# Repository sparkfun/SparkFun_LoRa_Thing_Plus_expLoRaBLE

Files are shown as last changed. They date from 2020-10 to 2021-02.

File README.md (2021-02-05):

SparkFun LoRa Thing Plus - expLoRaBLE
========================================

SparkFun LoRa Thing Plus - expLoRaBLE

[*SparkFun LoRa Thing Plus - expLoRaBLE (WRL-17506)*](https://www.sparkfun.com/products/17506)

The SparkFun LoRa Thing Plus - expLoRaBLE is a wireless development board in Thing Plus form factor that includes the NM180100 LoRa® Bluetooth® 5 Low Energy SiP. It is a global IoT solution ideal for long range, low power applications combining the transmit power of Semtech's LoRa® SX1262 with the processing power of Ambiq Micro's Apollo3 Blue.

Repository Contents
-------------------

* **/Documentation** - Data sheets, additional product information
* **/Hardware** - Eagle design files (.brd, .sch)
* **/Hardware/Production** - Production panel files (.brd)

Documentation
--------------
* **[Hookup Guide](https://learn.sparkfun.com/tutorials/sparkfun-explorable-hookup-guide)** - Basic hookup guide for the [LoRa Thing Plus - expLoRaBLE](https://www.sparkfun.com/products/17506).

License Information
-------------------

This product is _**open source**_! 

Please review the LICENSE.md file for license information. 

If you have any questions or concerns on licensing, please contact technical support on our [SparkFun forums](https://forum.sparkfun.com/viewforum.php?f=152).

Distributed as-is; no warranty is given.

- Your friends at SparkFun.

_<COLLABORATION CREDIT>_

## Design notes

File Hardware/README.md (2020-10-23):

SparkFun LoRa Thing Plus - expLoRaBLE Design Files
=====================================

The .sch and .brd files hare are Eagle CAD schematic and PCB design files from SparkFun Electronics.
A freeware version of Autodesk Eagle can be found [here](https://www.autodesk.com/products/eagle/free-download).

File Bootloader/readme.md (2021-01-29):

## Programming info0 binary

Note, to program info0 properly, do these things:

1. Clone this repo.
2. Open a CMD window.
3. Navigate to the bootloader directory of this repo.
4. Run JLINK with the included commandfile like so:

* *"C:\Program Files (x86)\SEGGER\JLink\jlink.exe" -CommanderScript jlink-prog-info0.txt*

## Special notes about programming

* You cannot effectively program info0 binaries using J-flash Light GUI. You must use JLINK commander with a commandfile. A command file can include calls to "ROM helper functions", which are essential to correctly (actually) programming the info0 memory locations on the MCU. [This screenshot](https://github.com/sparkfun/SparkFun_LoRa_Thing_Plus_expLoRaBLE/blob/master/Documentation/programming_script_screenshot_highligh.png) shows the commands to the ROM helper functions.

* You can call Jlink.exe from command line with the commandfile as an argument. Note, you may have to include the complete paths to jlink.exe and the commanderfile. Also note, you need to navigate your CMD into this directory first.

* *C:\Users\pete.lewis\Documents\GitHub\SparkFun_LoRa_Thing_Plus_expLoRaBLE\Bootloader>"C:\Program Files (x86)\SEGGER\JLink\jlink.exe" -CommanderScript jlink-prog-info0.txt*

This is the readout you should see:

    C:\Users\pete.lewis\Documents\GitHub\SparkFun_LoRa_Thing_Plus_expLoRaBLE\Bootloader>"C:\Program Files (x86)\SEGGER\JLink\jlink.exe" -CommanderScript jlink-prog-info0.txt
    SEGGER J-Link Commander V6.92 (Compiled Dec 18 2020 13:13:50)
    DLL version V6.92, compiled Dec 18 2020 13:12:28

    J-Link Command File read successfully.
    Processing script file...

    J-Link connection not established yet but required for command.
    Connecting to J-Link via USB...O.K.
    Firmware: J-Link EDU Mini V1 compiled Nov 12 2020 13:31:42
    Hardware version: V1.00
    S/N: 801028773
    License(s): FlashBP, GDB
    VTref=3.283V

    Selecting SWD as current target interface.

    Selecting 1000 kHz as target interface speed

    Target connection not established yet but required for command.
    Device "AMA3B1KK-KBR" selected.

    Connecting to target via SWD
    Found SW-DP with ID 0x2BA01477
    DPIDR: 0x2BA01477
    Scanning AP map to find all available APs
    AP[1]: Stopped AP scan as end of AP map has been reached
    AP[0]: AHB-AP (IDR: 0x24770011)
    Iterating through AP map to find AHB-AP to use
    AP[0]: Core found
    AP[0]: AHB-AP ROM base: 0xE00FF000
    CPUID register: 0x410FC241. Implementer code: 0x41 (ARM)
    Found Cortex-M4 r0p1, Little endian.
    FPUnit: 6 code (BP) slots and 2 literal slots
    CoreSight components:
    ROMTbl[0] @ E00FF000
    ROMTbl[0][0]: E000E000, CID: B105E00D, PID: 000BB00C SCS-M7
    ROMTbl[0][1]: E0001000, CID: B105E00D, PID: 003BB002 DWT
    ROMTbl[0][2]: E0002000, CID: B105E00D, PID: 002BB003 FPB
    ROMTbl[0][3]: E0000000, CID: B105E00D, PID: 003BB001 ITM
    ROMTbl[0][4]: E0040000, CID: B105900D, PID: 000BB9A1 TPIU
    Cortex-M4 identified.
    Reset delay: 0 ms
    Reset type NORMAL: Resets core & peripherals via SYSRESETREQ & VECTRESET bit.
    ResetTarget() start
    JDEC PID 0x000000CF
    Ambiq Apollo3 ResetTarget
    Bootldr = 0x04000000
    Secure Part.
    Secure Chip. Bootloader needs to run which will then halt when finish.
    CPU halted after reset. TryCount = 0x00000000
    ResetTarget() end

    Sleep(10)

    MSP = 0x10000100

    Writing 00000000 -> 10000000

    Writing D894E09E -> 10000004

    Writing FFFFFFFF -> 10000008

    Sleep(50)

    10000008 = 00000000

    Writing 00000000 -> 10000000

    Writing 00000000 -> 10000004

    Writing 00000800 -> 10000008

    Writing D894E09E -> 1000000C

    Writing FFFFFFFF -> 10000010

    Downloading file [info0_115200_bootGPIO22_active_high.bin]...
    O.K.

    Sleep(50)

    10000010 = 00000000

    Writing 0000001B -> 40000004

    Script processing completed.

## Info0 binary creation info

This was used to create the info0 file to work with the Ambiq Secure Bootloader in the expLoRaBLE design:

    python create_info0.py --valid 1 info0_115200_gpio22_active_high --pl 1 --u0 0x1c200c0 --u1 0xFFFF3031 --u2 0x2 --u3 0x0 --u4 0x0 --u5 0x0 --main 0xC000 --gpio 0x16 --version 0 --wTO 2500 --gpiolvl 1 --chip apollo3

Where:
* --u0 0x1C200c0 = 115200 baud (0x1c200)
* --main 0xC000 = main image location (0xC000)
* -- u1 0xFFFF3031 = UART-TX (0x30 - pin 48) and UART-RX (0x31 - pin 49)
* --gpio 0x16 = GPIO override *for the boot pin* (0x16, GPIO22)
* --gpiolvl 1 = active high boot setup (note, the default is active low, and the only SFE design as of 1/29/2021 that had active low was the edge, all others (e.g. the artemis and expLoRaBLE) are active high setups)
* --wTO 2500 = timeout failures set to 2500ms

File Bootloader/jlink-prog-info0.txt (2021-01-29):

// connect to device
// NEED to specify -device AMA3B2KK-KBR (for Apollo3P) or -device AMA3B1KK-KBR/KCR (for Apollo3) from command line

device AMA3B1KK-KBR

si SWD
speed 1000
r
sleep 10

//set C runtime environment
wreg MSP, 0x10000100 

// erase info0
w4 0x10000000 0             // flash info instance
w4 0x10000004 0xd894e09e    // info 0 key
w4 0x10000008 0xFFFFFFFF    // clear return value
setPC 0x08000085            // call the ROM helper function flash_info_erase_from_sram
g
sleep 50
mem32 0x10000008 1          // dump return value for check

// program info0
w4 0x10000000 0             // flash info instance
w4 0x10000004 0             // offset
w4 0x10000008 0x800         // length in words
w4 0x1000000C 0xd894e09e    // info 0 key
w4 0x10000010 0xFFFFFFFF    // clear return value
loadbin info0_115200_bootGPIO22_active_high.bin 0x10001000     //load the info0 binary into sram
setPC 0x08000061            // call the ROM helper function flash_program_info_area_from_sram
g
sleep 50
mem32 0x10000010 1          // dump return value for check

// perform software POI
w4 0x40000004 0x1B

// quit
qc

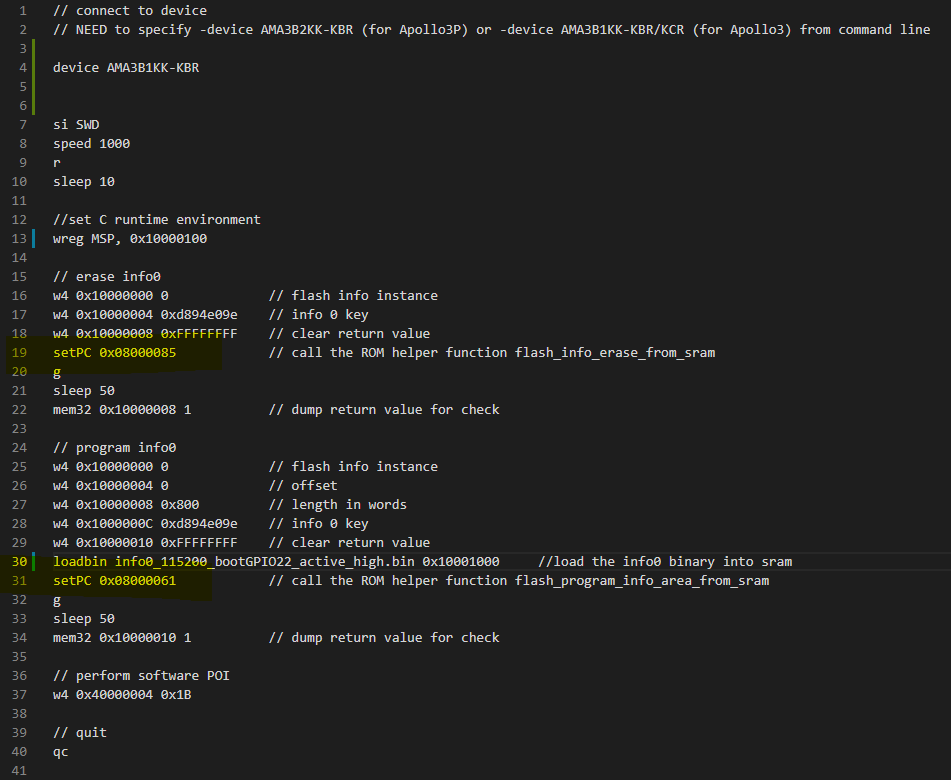
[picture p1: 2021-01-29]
Documentation/programming_script_screenshot_highligh.png

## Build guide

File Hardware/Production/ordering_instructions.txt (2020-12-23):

panel size, 131x201mm
PCB thickness, 1.6mm
number of layers, 4
soldermask color, Red
silkscreen color, White
oz copper, 1oz
finish, HASL lead free
stencils, top
pcs per panel, 15
min trace width, 0.1524mm / 0.0060in
min drill size, 0.2032mm / 0.0080in
filename to layer stackup 1/2/3/4: GTL, GL2, GL3, GBL

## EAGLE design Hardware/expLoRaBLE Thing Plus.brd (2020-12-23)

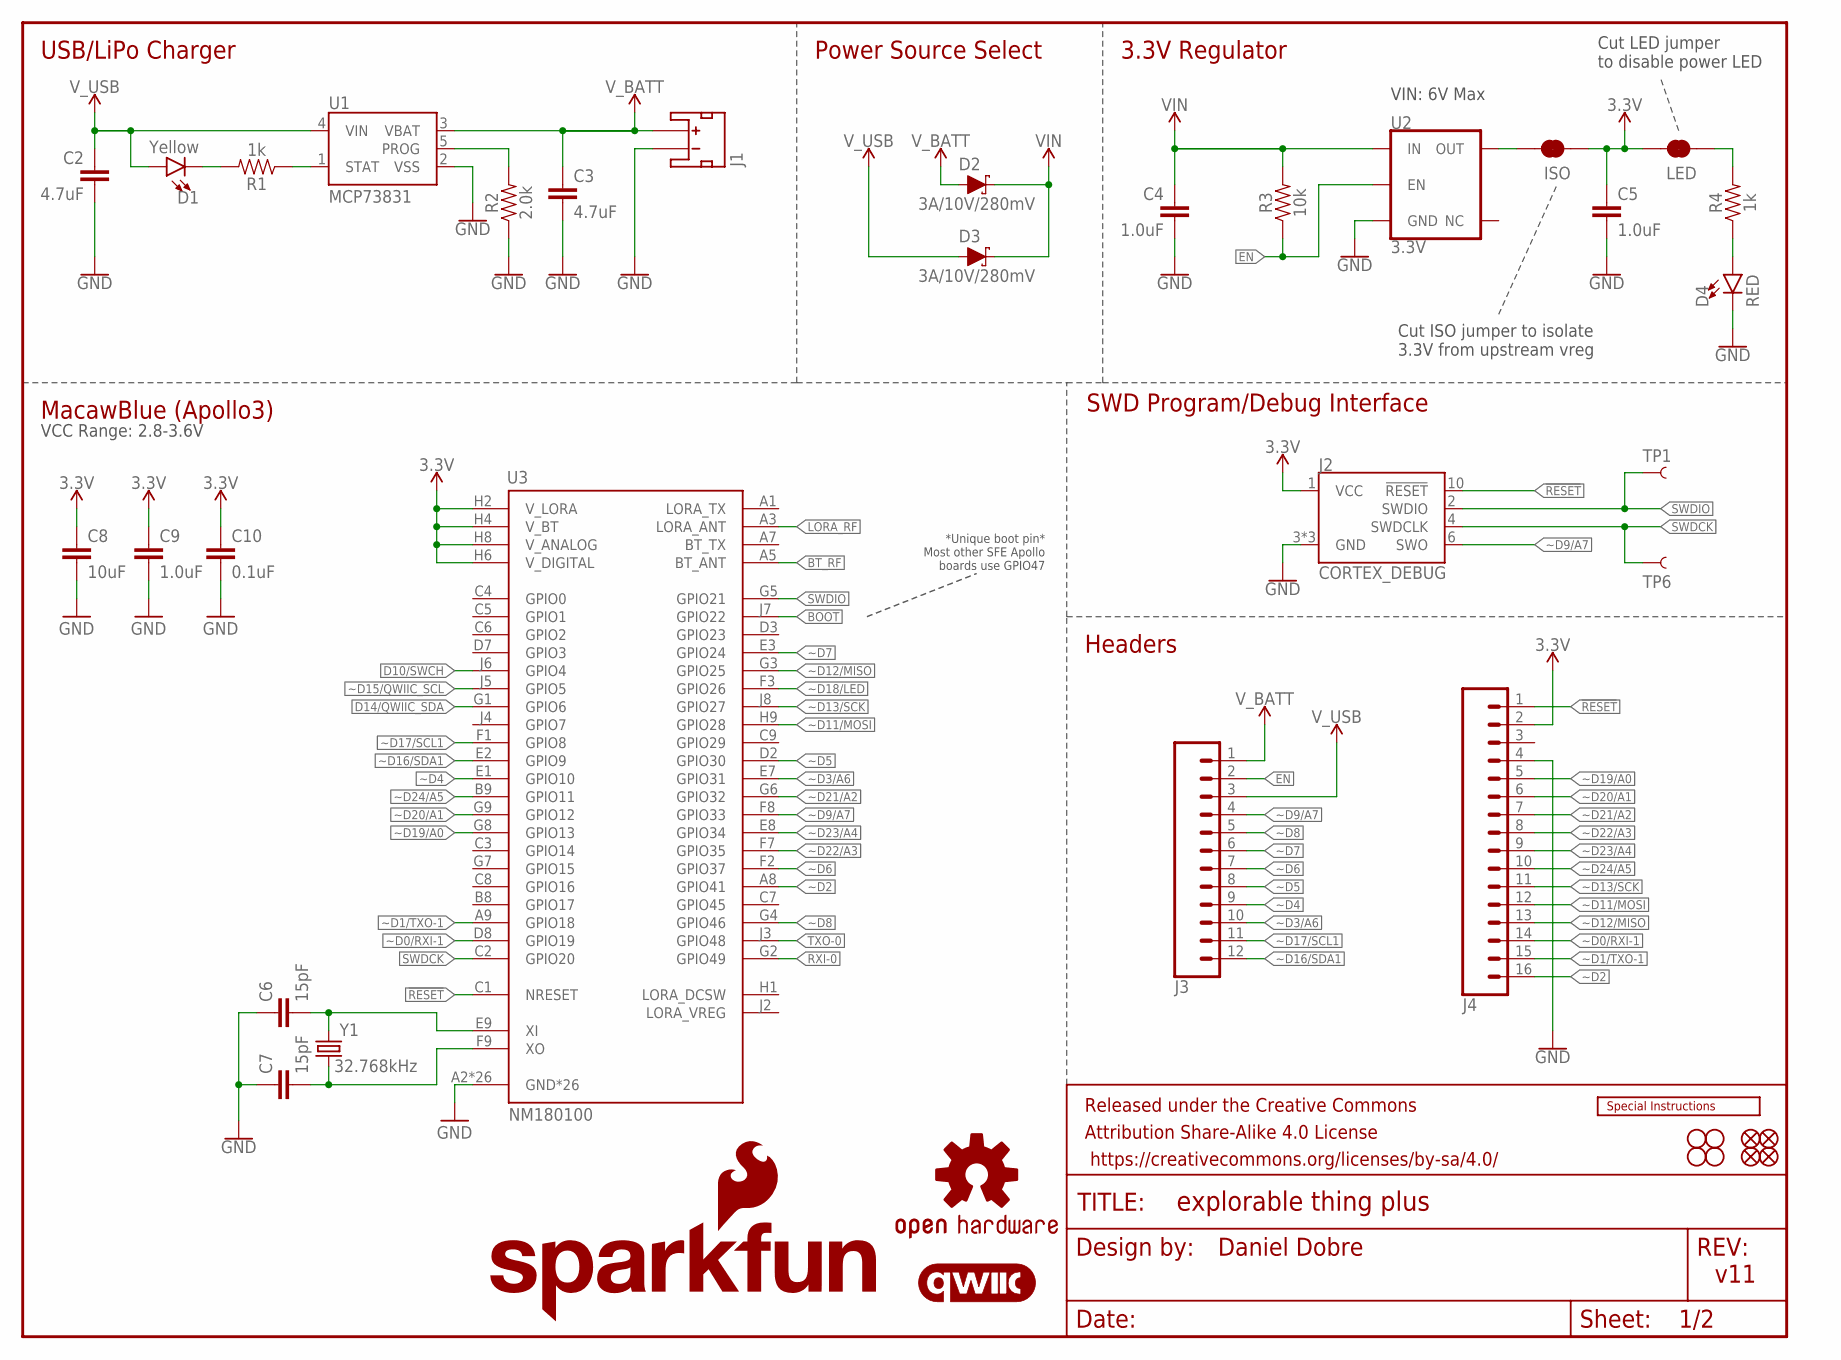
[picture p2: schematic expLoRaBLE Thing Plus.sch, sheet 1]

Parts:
C2, C3: 4.7uF; 0603
C4, C5, C9: 1.0uF; 0603
C6, C7: 15pF; 0603
C8: 10uF; 0603
C10: 0.1uF; 0603
D1: Yellow; LED-0603
D2, D3: 3A/10V/280mV; SOD-323
D4: RED; LED-0603
FD1, FD2, FD3, FD4: FIDUCIALUFIDUCIAL; FIDUCIAL-MICRO
FRAME1: FRAME-LETTER; CREATIVE_COMMONS
H1, H2, H3, H4: STAND-OFF
ISO: JUMPER-SMT_2_NC_TRACE_SILK; SMT-JUMPER_2_NC_TRACE_SILK
J1: JST_2MM_MALE; JST-2-SMD
J2: CORTEX_DEBUG; 2X5-PTH-1.27MM-NO_SILK
J3: CONN_12SM_SQ_NO_SILK; 1X12_SM_SQ_NOSILK
J4: CONN_161X16_SM_SQ_NOSILK; 1X16_SM_SQ_NOSILK
LED: JUMPER-SMT_2_NC_TRACE_SILK; SMT-JUMPER_2_NC_TRACE_SILK
LOGO1: OSHW-LOGOS; OSHW-LOGO-S
LOGO2: QWIIC_LOGO_5MM; QWIIC_5MM
LOGO3: SFE_LOGO_NAME_FLAME.1_INCH; SFE_LOGO_NAME_FLAME_.1
LOGO4: SPECIAL_INSTRUCTIONS-ORDERING; ORDERING_INSTRUCTIONS
R1, R4: 1k; 0603
R2: 2.0k; 0603
R3: 10k; 0603
TP1, TP6: TEST-POINTTP_15TH_THRU; TP_15TH
U1: MCP73831; SOT23-5
U2: 3.3V; SOT23-5
U3: NM180100; LGA81
Y1: 32.768kHz; CRYSTAL-SMD-3.2X1.5MM

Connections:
3.3V: C5.1, C8.1, C9.1, C10.1, ISO.1, J2.1 (VCC), J4.2, LED.2, U3.H2 (V_LORA), U3.H4 (V_BT), U3.H6 (V_DIGITAL), U3.H8 (V_ANALOG); also elsewhere on the board
!RESET: J2.10 (!RESET), J4.1, U3.C1 (NRESET); also elsewhere on the board
BOOT: U3.J7 (GPIO22); also elsewhere on the board
BT_RF: U3.A5 (BT_ANT); also elsewhere on the board
D10/SWCH: U3.J6 (GPIO4); also elsewhere on the board
D14/QWIIC_SDA: U3.G1 (GPIO6); also elsewhere on the board
EN: J3.2, R3.1, U2.3 (EN)
GND: C2.2, C3.2, C4.2, C5.2, C6.1, C7.1, C8.2, C9.2, C10.2, D4.C, J1.1 (-), J2.3 (GND), J2.5 (GND), J2.9 (GND), J4.4, R2.1, U1.2 (VSS), U2.2 (GND), U3.A2 (GND*26), U3.A4 (GND*26), U3.A6 (GND*26), U3.B1 (GND*26), U3.B2 (GND*26), U3.B3 (GND*26), U3.B4 (GND*26), U3.B5 (GND*26), U3.B6 (GND*26), U3.B7 (GND*26), U3.D1 (GND*26), U3.D4 (GND*26), U3.D5 (GND*26), U3.D6 (GND*26), U3.D9 (GND*26), U3.E4 (GND*26), U3.E5 (GND*26), U3.E6 (GND*26), U3.F4 (GND*26), U3.F5 (GND*26), U3.F6 (GND*26), U3.H3 (GND*26), U3.H5 (GND*26), U3.H7 (GND*26), U3.J1 (GND*26), U3.J9 (GND*26); also elsewhere on the board
LORA_RF: U3.A3 (LORA_ANT); also elsewhere on the board
unnamed: R2.2, U1.5 (PROG)
unnamed: C7.2, U3.F9 (XO), Y1.P$2 (2)
unnamed: D1.C, R1.2
unnamed: R1.1, U1.1 (STAT)
unnamed: LED.1, R4.2
unnamed: C6.2, U3.E9 (XI), Y1.P$1 (1)
unnamed: D4.A, R4.1
unnamed: ISO.2, U2.5 (OUT)
RXI-0: U3.G2 (GPIO49); also elsewhere on the board
SWDCK: J2.4 (SWDCLK), TP6.P$1, U3.C2 (GPIO20)
SWDIO: J2.2 (SWDIO), TP1.P$1, U3.G5 (GPIO21)
TXO-0: U3.J3 (GPIO48); also elsewhere on the board
VIN: C4.1, D2.C, D3.C, R3.2, U2.1 (IN)
V_BATT: C3.1, D2.A, J1.2 (+), J3.1, U1.3 (VBAT)
V_USB: C2.1, D1.A, D3.A, J3.3, U1.4 (VIN); also elsewhere on the board
~D0/RXI-1: J4.14, U3.D8 (GPIO19)
~D1/TXO-1: J4.15, U3.A9 (GPIO18)
~D2: J4.16, U3.A8 (GPIO41)
~D3/A6: J3.10, U3.E7 (GPIO31)
~D4: J3.9, U3.E1 (GPIO10)
~D5: J3.8, U3.D2 (GPIO30)
~D6: J3.7, U3.F2 (GPIO37)
~D7: J3.6, U3.E3 (GPIO24)
~D8: J3.5, U3.G4 (GPIO46)
~D9/A7: J2.6 (SWO), J3.4, U3.F8 (GPIO33)
~D11/MOSI: J4.12, U3.H9 (GPIO28)
~D12/MISO: J4.13, U3.G3 (GPIO25)
~D13/SCK: J4.11, U3.J8 (GPIO27)
~D15/QWIIC_SCL: U3.J5 (GPIO5); also elsewhere on the board
~D16/SDA1: J3.12, U3.E2 (GPIO9)
~D17/SCL1: J3.11, U3.F1 (GPIO8)
~D18/LED: U3.F3 (GPIO26); also elsewhere on the board
~D19/A0: J4.5, U3.G8 (GPIO13)
~D20/A1: J4.6, U3.G9 (GPIO12)
~D21/A2: J4.7, U3.G6 (GPIO32)
~D22/A3: J4.8, U3.F7 (GPIO35)
~D23/A4: J4.9, U3.E8 (GPIO34)
~D24/A5: J4.10, U3.B9 (GPIO11)

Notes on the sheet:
SWD Program/Debug Interface
Headers
MacawBlue (Apollo3)
USB/LiPo Charger
Power Source Select
3.3V Regulator
VIN: 6V Max
Daniel Dobre
v11
Cut LED jumper to disable power LED
Cut ISO jumper to isolate 3.3V from upstream vreg
VCC Range: 2.8-3.6V
*Unique boot pin* Most other SFE Apollo boards use GPIO47

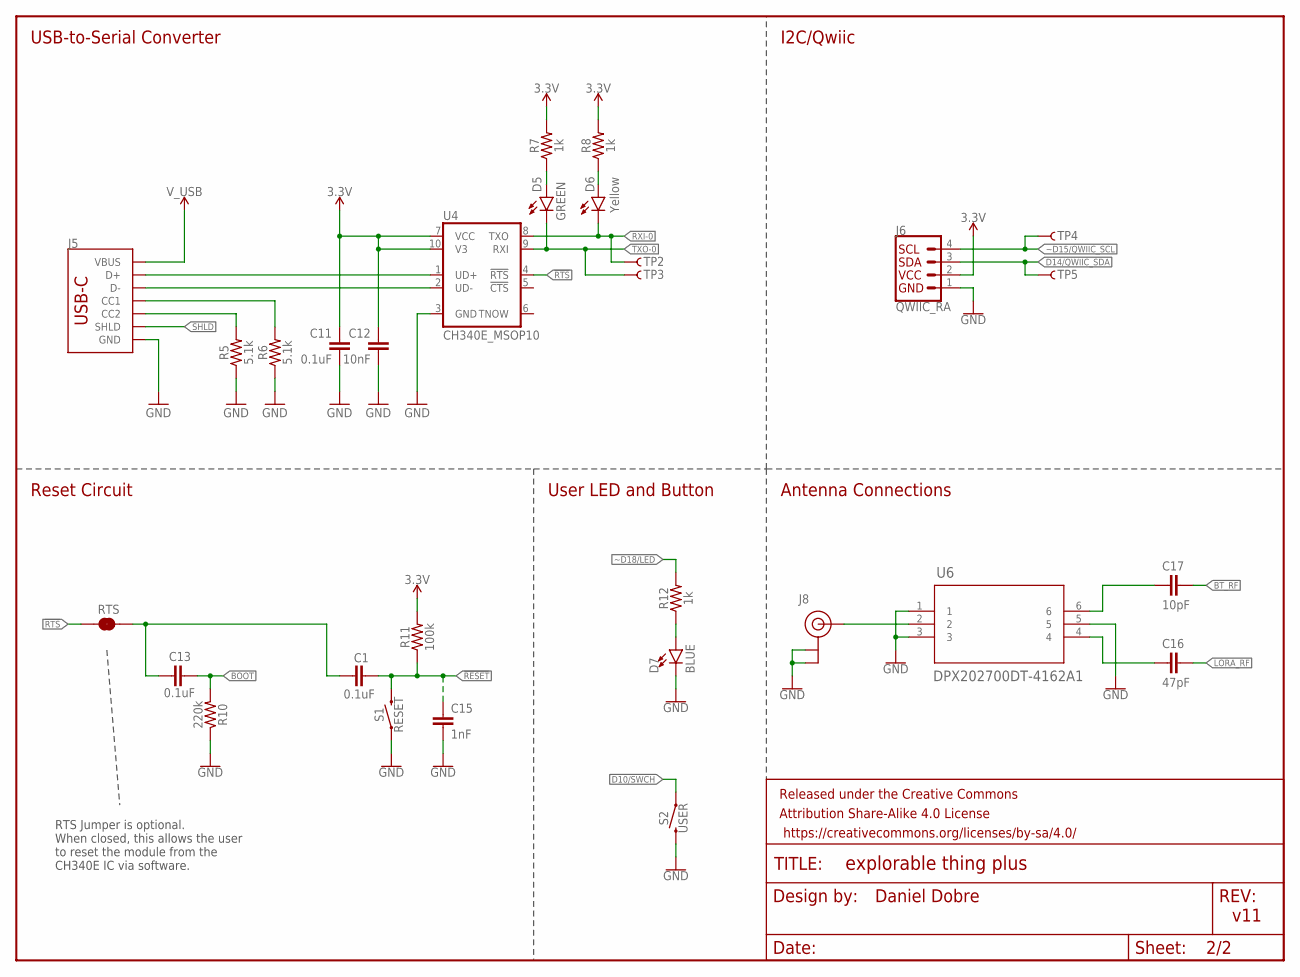
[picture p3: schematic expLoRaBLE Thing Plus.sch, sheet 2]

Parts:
C1, C11, C13: 0.1uF; 0603
C12: 10nF; 0603
C15: 1nF; 0603
C16: 47pF; 0603
C17: 10pF; 0603
D5: GREEN; LED-0603
D6: Yellow; LED-0603
D7: BLUE; LED-0603
FRAME2: FRAME-LETTERNO_PACKAGE; DUMMY
J5: USB Female Type C Connector; USB-C-16P-4LAYER-ISOLATED
J6: QWIIC_RA; JST04_1MM_RA
J8: U.FL
R5, R6: 5.1k; 0603
R7, R8, R12: 1k; 0603
R10: 220k; 0603
R11: 100k; 0603
RTS: JUMPER-SMT_2_NC_TRACE_SILK; SMT-JUMPER_2_NC_TRACE_SILK
S1: RESET; TACTILE_SWITCH_SMD_4.6X2.8MM
S2: USER; TACTILE_SWITCH_SMD_4.6X2.8MM
TP2, TP3, TP4, TP5: TEST-POINTTP_15TH_THRU; TP_15TH
U4: CH340E_MSOP10; MSOP10
U6: DPX202700DT-4162A1; RF_4060A1_TDK

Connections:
3.3V: C11.1, C12.1, J6.2, R7.2, R8.2, R11.2, U4.7 (VCC), U4.10 (V3); also elsewhere on the board
!RESET: C1.2, C15.1, R11.1, S1.3 (2), S1.4 (2); also elsewhere on the board
!RTS: RTS.1, U4.4 (!RTS)
BOOT: C13.2, R10.2; also elsewhere on the board
BT_RF: C17.1; also elsewhere on the board
CC1: J5.A5 (CC1), R6.2
CC2: J5.B5 (CC2), R5.2
D10/SWCH: S2.1, S2.2 (1); also elsewhere on the board
D14/QWIIC_SDA: J6.3, TP5.P$1; also elsewhere on the board
D+1: J5.A6 (D+), J5.B6 (D+), U4.1 (UD+)
D-1: J5.A7 (D-), J5.B7 (D-), U4.2 (UD-)
GND: C11.2, C12.2, C15.2, D7.C, J5.GND, J5.GND2 (GND), J6.1, J8.1 (GND), J8.2 (GND), R5.1, R6.1, R10.1, S1.1, S1.2 (1), S2.3 (2), S2.4 (2), U4.3 (GND), U6.1, U6.3, U6.5; also elsewhere on the board
LORA_RF: C16.1; also elsewhere on the board
unnamed: D5.A, R7.1
unnamed: D7.A, R12.1
unnamed: D6.A, R8.1
unnamed: C17.2, U6.6
unnamed: J8.FEED (SIGNAL), U6.2
unnamed: C16.2, U6.4
unnamed: C1.1, C13.1, RTS.2
RXI-0: D6.C, TP2.P$1, U4.8 (TXO); also elsewhere on the board
SHLD: J5.SHLD1 (SHLD), J5.SHLD2 (SHLD), J5.SHLD3 (SHLD), J5.SHLD4 (SHLD), J5.SHLD5 (SHLD), J5.SHLD6 (SHLD), J5.SHLD7 (SHLD), J5.SHLD8 (SHLD)
TXO-0: D5.C, TP3.P$1, U4.9 (RXI); also elsewhere on the board
V_USB: J5.VBUS1 (VBUS), J5.VBUS2 (VBUS); also elsewhere on the board
~D15/QWIIC_SCL: J6.4, TP4.P$1; also elsewhere on the board
~D18/LED: R12.2; also elsewhere on the board

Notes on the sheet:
Antenna Connections
USB-to-Serial Converter
Reset Circuit
User LED and Button
I2C/Qwiic
Daniel Dobre
v11
RTS Jumper is optional. When closed, this allows the user to reset the module from the CH340E IC via software.

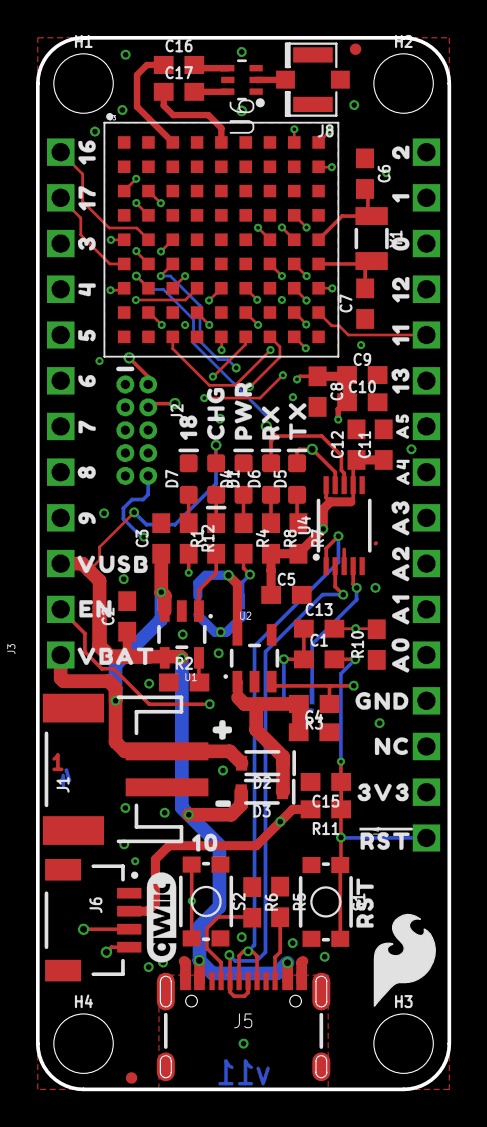
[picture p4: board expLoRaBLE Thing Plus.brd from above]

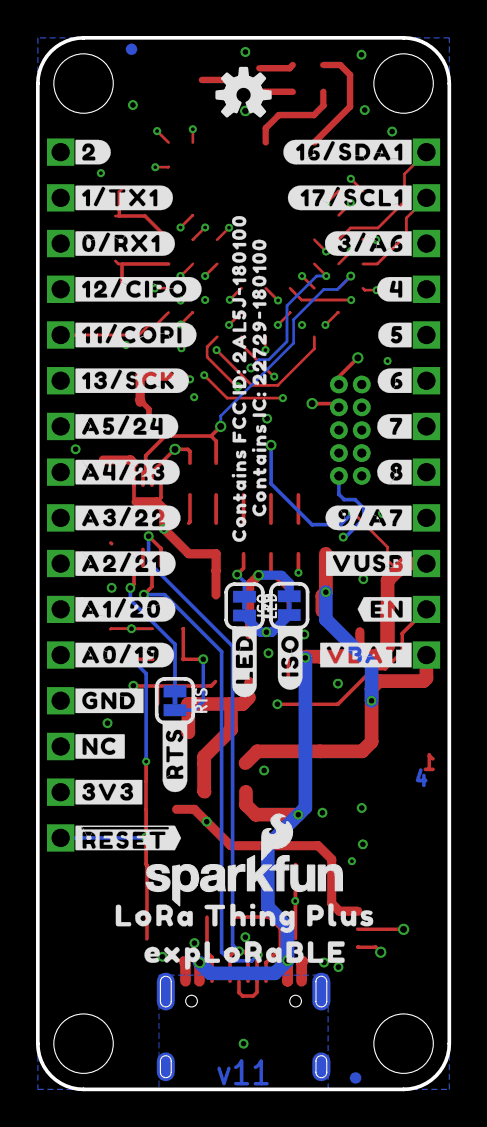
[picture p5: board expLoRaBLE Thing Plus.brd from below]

Board: 4 copper layers, 22.9 x 58.4 mm, 146 parts (42 on the bottom side), 60 nets.

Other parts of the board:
U$1: #16#SDA1#0
U$2: LORA_THING_PLUS0
U$3: EXPLORABLE0
U$4: #17#SCL1#0
U$5: #3#A6#0
U$6: #4#0
U$7: #5#0
U$8: #6#0
U$9: #7#0
U$10: #8#0
U$11: #9#A7#0
U$12: #VUSB#0
U$13: VUSB0
U$14: #EN#0
U$15: #VBAT#0
U$16: #2#0
U$17: #1#TX1#0
U$18: #0#RX1#0
U$19: #12#CIPO#0
U$20: #11#COPI#0
U$21: #13#SCK#0
U$22: CONTAINS_FCC_ID#_2AL5J#1801000
U$23: CONTAINS_IC#_22729#1801000
U$24: #RTS#0
U$28: #GND#0
U$29: #NC#0
U$30: #3V3#0
U$31: ##RESET##0
U$32: #LED#0
U$33: #A0#19#0
U$34: #ISO#0
U$35: #A1#20#0
U$36: #A2#21#0
U$37: #A3#22#0
U$38: #A4#23#0
U$39: #A5#24#0
U$62: 180
U$64: FOUR_LAYER_WARNING
U$65: SFE_LOGO_FLAME_.2
U$66: 160
U$67: CHG0
U$68: PWR0
U$69: 170
U$70: 30
U$71: 40
U$72: 50
U$73: 60
U$74: 70
U$75: 80
U$76: 90
U$78: EN0
U$79: VBAT0
U$80: 20
U$81: 10
U$82: 00
U$83: 120
U$84: 110
U$85: 130
U$86: A50
U$87: A40
U$88: A30
U$89: A20
U$90: A10
U$91: A00
U$92: GND0
U$93: NC0
U$94: 3V30
U$95: #RST#0
U$96: RST0
U$97: 100
U$98: #0
U$99: #_0
U$100: RX0
U$101: TX0

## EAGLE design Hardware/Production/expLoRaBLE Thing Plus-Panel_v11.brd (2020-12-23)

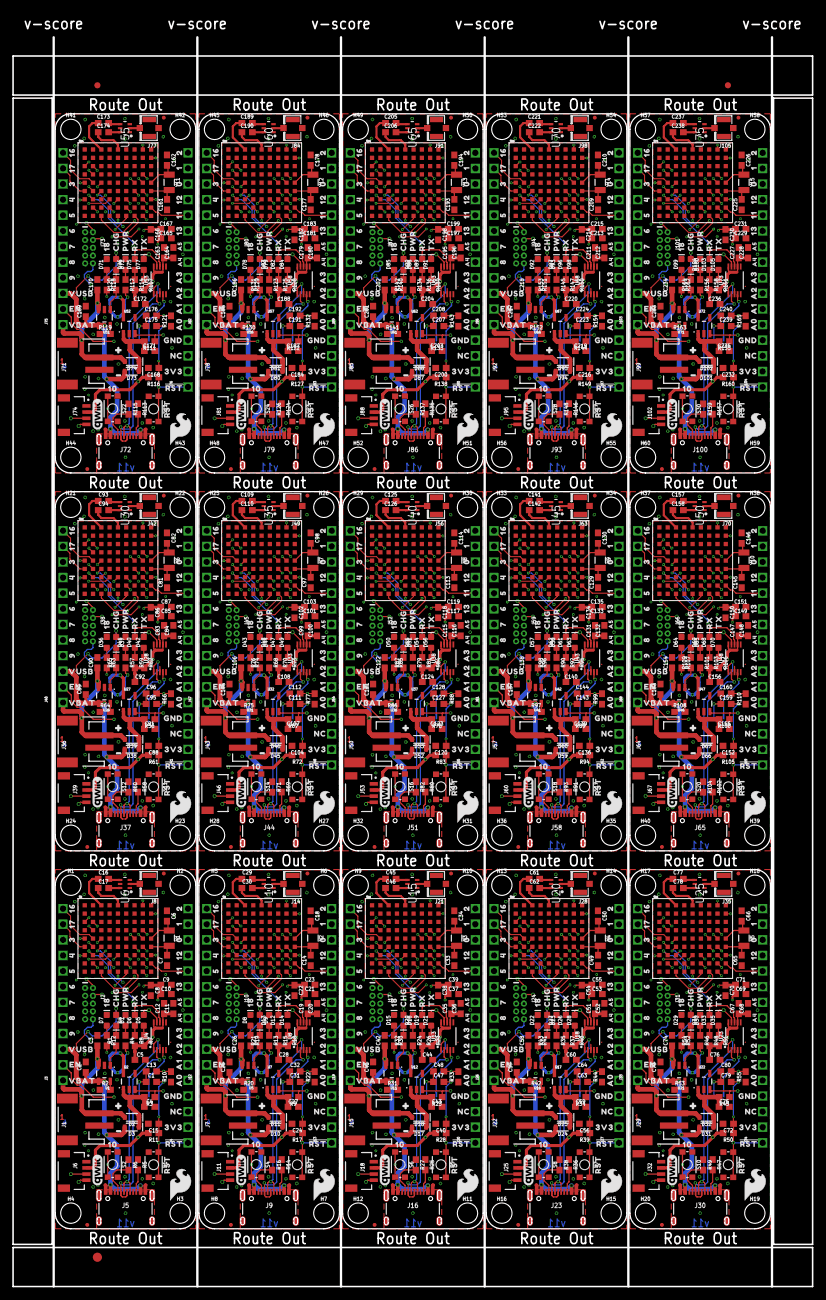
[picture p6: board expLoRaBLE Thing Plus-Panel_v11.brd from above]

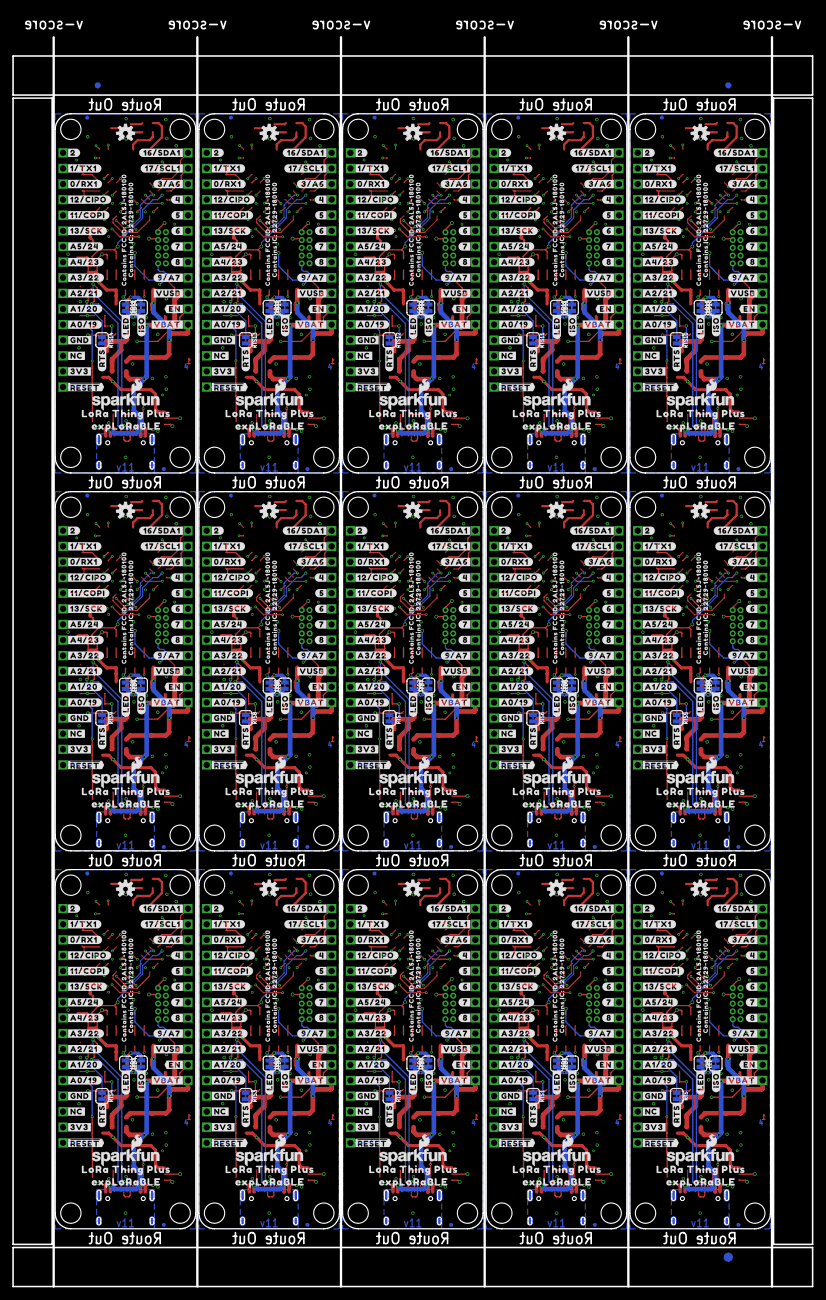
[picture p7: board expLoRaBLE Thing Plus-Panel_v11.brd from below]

Board: 4 copper layers, 130.0 x 203.2 mm, 2181 parts (633 on the bottom side), 900 nets.

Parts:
C1, C10, C11, C13, C20, C21, C31, C32, C36, C37, C47, C48, C52, C53, C63, C64, C68, C69, C79, C80, C84, C85, C95, C96, C100, C101, C111, C112, C116, C117, C127, C128, C132, C133, C143, C144, C148, C149, C159, C160, C164, C165, C175, C176, C180, C181, C191, C192, C196, C197, C207, C208, C212, C213, C223, C224, C228, C229, C239, C240: 0.1uF; 0603
C2, C3, C25, C26, C41, C42, C57, C58, C73, C74, C89, C90, C105, C106, C121, C122, C137, C138, C153, C154, C169, C170, C185, C186, C201, C202, C217, C218, C233, C234: 4.7uF; 0603
C4, C5, C9, C23, C27, C28, C39, C43, C44, C55, C59, C60, C71, C75, C76, C87, C91, C92, C103, C107, C108, C119, C123, C124, C135, C139, C140, C151, C155, C156, C167, C171, C172, C183, C187, C188, C199, C203, C204, C215, C219, C220, C231, C235, C236: 1.0uF; 0603
C6, C7, C14, C18, C33, C34, C49, C50, C65, C66, C81, C82, C97, C98, C113, C114, C129, C130, C145, C146, C161, C162, C177, C178, C193, C194, C209, C210, C225, C226: 15pF; 0603
C8, C22, C38, C54, C70, C86, C102, C118, C134, C150, C166, C182, C198, C214, C230: 10uF; 0603
C12, C19, C35, C51, C67, C83, C99, C115, C131, C147, C163, C179, C195, C211, C227: 10nF; 0603
C15, C24, C40, C56, C72, C88, C104, C120, C136, C152, C168, C184, C200, C216, C232: 1nF; 0603
C16, C29, C45, C61, C77, C93, C109, C125, C141, C157, C173, C189, C205, C221, C237: 47pF; 0603
C17, C30, C46, C62, C78, C94, C110, C126, C142, C158, C174, C190, C206, C222, C238: 10pF; 0603
D1, D6, D9, D12, D16, D19, D23, D26, D30, D33, D37, D40, D44, D47, D51, D54, D58, D61, D65, D68, D72, D75, D79, D82, D86, D89, D93, D96, D100, D103: Yellow; LED-0603
D2, D3, D10, D11, D17, D18, D24, D25, D31, D32, D38, D39, D45, D46, D52, D53, D59, D60, D66, D67, D73, D74, D80, D81, D87, D88, D94, D95, D101, D102: 3A/10V/280mV; SOD-323
D4, D13, D20, D27, D34, D41, D48, D55, D62, D69, D76, D83, D90, D97, D104: RED; LED-0603
D5, D14, D21, D28, D35, D42, D49, D56, D63, D70, D77, D84, D91, D98, D105: GREEN; LED-0603
D7, D8, D15, D22, D29, D36, D43, D50, D57, D64, D71, D78, D85, D92, D99: BLUE; LED-0603
E$1, E$2, E$3, E$4: FIDUCIAL-1X2
E$5, E$6: FIDUCIAL-1.5X3
FD1, FD2, FD3, FD4, FD5, FD6, FD7, FD8, FD9, FD10, FD11, FD12, FD13, FD14, FD15, FD16, FD17, FD18, FD19, FD20, FD21, FD22, FD23, FD24, FD25, FD26, FD27, FD28, FD29, FD30, FD31, FD32, FD33, FD34, FD35, FD36, FD37, FD38, FD39, FD40, FD41, FD42, FD43, FD44, FD45, FD46, FD47, FD48, FD49, FD50, FD51, FD52, FD53, FD54, FD55, FD56, FD57, FD58, FD59, FD60: FIDUCIALUFIDUCIAL; FIDUCIAL-MICRO
FRAME1, FRAME3, FRAME5, FRAME7, FRAME9, FRAME11, FRAME13, FRAME15, FRAME17, FRAME19, FRAME21, FRAME23, FRAME25, FRAME27, FRAME29: FRAME-LETTER; CREATIVE_COMMONS
FRAME2, FRAME4, FRAME6, FRAME8, FRAME10, FRAME12, FRAME14, FRAME16, FRAME18, FRAME20, FRAME22, FRAME24, FRAME26, FRAME28, FRAME30: FRAME-LETTERNO_PACKAGE; DUMMY
H1, H2, H3, H4, H5, H6, H7, H8, H9, H10, H11, H12, H13, H14, H15, H16, H17, H18, H19, H20, H21, H22, H23, H24, H25, H26, H27, H28, H29, H30, H31, H32, H33, H34, H35, H36, H37, H38, H39, H40, H41, H42, H43, H44, H45, H46, H47, H48, H49, H50, H51, H52, H53, H54, H55, H56, H57, H58, H59, H60: STAND-OFF
ISO, ISO1, ISO2, ISO3, ISO4, ISO5, ISO6, ISO7, ISO8, ISO9, ISO10, ISO11, ISO12, ISO13, ISO14: JUMPER-SMT_2_NC_TRACE_SILK; SMT-JUMPER_2_NC_TRACE_SILK
J1, J7, J15, J22, J29, J36, J43, J50, J57, J64, J71, J78, J85, J92, J99: JST-2-SMD
J2, J10, J17, J24, J31, J38, J45, J52, J59, J66, J73, J80, J87, J94, J101: CORTEX_DEBUG; 2X5-PTH-1.27MM-NO_SILK
J3, J12, J19, J26, J33, J40, J47, J54, J61, J68, J75, J82, J89, J96, J103: 1X12_SM_SQ_NOSILK
J4, J13, J20, J27, J34, J41, J48, J55, J62, J69, J76, J83, J90, J97, J104: 1X16_SM_SQ_NOSILK
J5, J9, J16, J23, J30, J37, J44, J51, J58, J65, J72, J79, J86, J93, J100: USB Female Type C Connector; USB-C-16P-4LAYER-ISOLATED
J6, J11, J18, J25, J32, J39, J46, J53, J60, J67, J74, J81, J88, J95, J102: QWIIC_RA; JST04_1MM_RA
J8, J14, J21, J28, J35, J42, J49, J56, J63, J70, J77, J84, J91, J98, J105: U.FL
LED, LED1, LED2, LED3, LED4, LED5, LED6, LED7, LED8, LED9, LED10, LED11, LED12, LED13, LED14: JUMPER-SMT_2_NC_TRACE_SILK; SMT-JUMPER_2_NC_TRACE_SILK
LOGO1, LOGO6, LOGO9, LOGO12, LOGO15, LOGO18, LOGO21, LOGO24, LOGO27, LOGO30, LOGO33, LOGO36, LOGO39, LOGO42, LOGO45: OSHW-LOGOS; OSHW-LOGO-S
LOGO2, LOGO4, LOGO7, LOGO10, LOGO13, LOGO16, LOGO19, LOGO22, LOGO25, LOGO28, LOGO31, LOGO34, LOGO37, LOGO40, LOGO43: QWIIC_LOGO_5MM; QWIIC_5MM
LOGO3, LOGO5, LOGO8, LOGO11, LOGO14, LOGO17, LOGO20, LOGO23, LOGO26, LOGO29, LOGO32, LOGO35, LOGO38, LOGO41, LOGO44: SFE_LOGO_NAME_FLAME.1_INCH; SFE_LOGO_NAME_FLAME_.1
R1, R4, R7, R8, R12, R13, R15, R18, R19, R21, R24, R26, R29, R30, R32, R35, R37, R40, R41, R43, R46, R48, R51, R52, R54, R57, R59, R62, R63, R65, R68, R70, R73, R74, R76, R79, R81, R84, R85, R87, R90, R92, R95, R96, R98, R101, R103, R106, R107, R109, R112, R114, R117, R118, R120, R123, R125, R128, R129, R131, R134, R136, R139, R140, R142, R145, R147, R150, R151, R153, R156, R158, R161, R162, R164: 1k; 0603
R2, R20, R31, R42, R53, R64, R75, R86, R97, R108, R119, R130, R141, R152, R163: 2.0k; 0603
R3, R9, R23, R34, R45, R56, R67, R78, R89, R100, R111, R122, R133, R144, R155: 10k; 0603
R5, R6, R14, R16, R25, R27, R36, R38, R47, R49, R58, R60, R69, R71, R80, R82, R91, R93, R102, R104, R113, R115, R124, R126, R135, R137, R146, R148, R157, R159: 5.1k; 0603
R10, R22, R33, R44, R55, R66, R77, R88, R99, R110, R121, R132, R143, R154, R165: 220k; 0603
R11, R17, R28, R39, R50, R61, R72, R83, R94, R105, R116, R127, R138, R149, R160: 100k; 0603
RTS, RTS1, RTS2, RTS3, RTS4, RTS5, RTS6, RTS7, RTS8, RTS9, RTS10, RTS11, RTS12, RTS13, RTS14: JUMPER-SMT_2_NC_TRACE_SILK; SMT-JUMPER_2_NC_TRACE_SILK
S1, S3, S5, S7, S9, S11, S13, S15, S17, S19, S21, S23, S25, S27, S29: RESET; TACTILE_SWITCH_SMD_4.6X2.8MM
S2, S4, S6, S8, S10, S12, S14, S16, S18, S20, S22, S24, S26, S28, S30: USER; TACTILE_SWITCH_SMD_4.6X2.8MM
TP1, TP2, TP3, TP4, TP5, TP6, TP7, TP8, TP9, TP10, TP11, TP12, TP13, TP14, TP15, TP16, TP17, TP18, TP19, TP20, TP21, TP22, TP23, TP24, TP25, TP26, TP27, TP28, TP29, TP30, TP31, TP32, TP33, TP34, TP35, TP36, TP37, TP38, TP39, TP40, TP41, TP42, TP43, TP44, TP45, TP46, TP47, TP48, TP49, TP50, TP51, TP52, TP53, TP54, TP55, TP56, TP57, TP58, TP59, TP60, TP61, TP62, TP63, TP64, TP65, TP66, TP67, TP68, TP69, TP70, TP71, TP72, TP73, TP74, TP75, TP76, TP77, TP78, TP79, TP80, TP81, TP82, TP83, TP84, TP85, TP86, TP87, TP88, TP89, TP90: TEST-POINTTP_15TH_THRU; TP_15TH
U1, U5, U11, U16, U21, U26, U31, U36, U41, U46, U51, U56, U61, U66, U71: MCP73831; SOT23-5
U2, U7, U12, U17, U22, U27, U32, U37, U42, U47, U52, U57, U62, U67, U72: 3.3V; SOT23-5
U3, U9, U14, U19, U24, U29, U34, U39, U44, U49, U54, U59, U64, U69, U74: NM180100; LGA81
U4, U8, U13, U18, U23, U28, U33, U38, U43, U48, U53, U58, U63, U68, U73: CH340E_MSOP10; MSOP10
U6, U10, U15, U20, U25, U30, U35, U40, U45, U50, U55, U60, U65, U70, U75: DPX202700DT-4162A1; RF_4060A1_TDK
U$1, U$115, U$189, U$263, U$337, U$411, U$485, U$559, U$633, U$707, U$781, U$855, U$929, U$1003, U$1077: #16#SDA1#0
U$2, U$113, U$187, U$261, U$335, U$409, U$483, U$557, U$631, U$705, U$779, U$853, U$927, U$1001, U$1075: LORA_THING_PLUS0
U$3, U$114, U$188, U$262, U$336, U$410, U$484, U$558, U$632, U$706, U$780, U$854, U$928, U$1002, U$1076: EXPLORABLE0
U$4, U$116, U$190, U$264, U$338, U$412, U$486, U$560, U$634, U$708, U$782, U$856, U$930, U$1004, U$1078: #17#SCL1#0
U$5, U$117, U$191, U$265, U$339, U$413, U$487, U$561, U$635, U$709, U$783, U$857, U$931, U$1005, U$1079: #3#A6#0
U$6, U$118, U$192, U$266, U$340, U$414, U$488, U$562, U$636, U$710, U$784, U$858, U$932, U$1006, U$1080: #4#0
U$7, U$119, U$193, U$267, U$341, U$415, U$489, U$563, U$637, U$711, U$785, U$859, U$933, U$1007, U$1081: #5#0
U$8, U$120, U$194, U$268, U$342, U$416, U$490, U$564, U$638, U$712, U$786, U$860, U$934, U$1008, U$1082: #6#0
U$9, U$121, U$195, U$269, U$343, U$417, U$491, U$565, U$639, U$713, U$787, U$861, U$935, U$1009, U$1083: #7#0
U$10, U$122, U$196, U$270, U$344, U$418, U$492, U$566, U$640, U$714, U$788, U$862, U$936, U$1010, U$1084: #8#0
U$11, U$123, U$197, U$271, U$345, U$419, U$493, U$567, U$641, U$715, U$789, U$863, U$937, U$1011, U$1085: #9#A7#0
U$12, U$124, U$198, U$272, U$346, U$420, U$494, U$568, U$642, U$716, U$790, U$864, U$938, U$1012, U$1086: #VUSB#0
U$13, U$125, U$199, U$273, U$347, U$421, U$495, U$569, U$643, U$717, U$791, U$865, U$939, U$1013, U$1087: VUSB0
U$14, U$126, U$200, U$274, U$348, U$422, U$496, U$570, U$644, U$718, U$792, U$866, U$940, U$1014, U$1088: #EN#0
U$15, U$127, U$201, U$275, U$349, U$423, U$497, U$571, U$645, U$719, U$793, U$867, U$941, U$1015, U$1089: #VBAT#0
U$16, U$128, U$202, U$276, U$350, U$424, U$498, U$572, U$646, U$720, U$794, U$868, U$942, U$1016, U$1090: #2#0
U$17, U$129, U$203, U$277, U$351, U$425, U$499, U$573, U$647, U$721, U$795, U$869, U$943, U$1017, U$1091: #1#TX1#0
U$18, U$130, U$204, U$278, U$352, U$426, U$500, U$574, U$648, U$722, U$796, U$870, U$944, U$1018, U$1092: #0#RX1#0
U$19, U$131, U$205, U$279, U$353, U$427, U$501, U$575, U$649, U$723, U$797, U$871, U$945, U$1019, U$1093: #12#CIPO#0
U$20, U$132, U$206, U$280, U$354, U$428, U$502, U$576, U$650, U$724, U$798, U$872, U$946, U$1020, U$1094: #11#COPI#0
U$21, U$133, U$207, U$281, U$355, U$429, U$503, U$577, U$651, U$725, U$799, U$873, U$947, U$1021, U$1095: #13#SCK#0
U$22, U$146, U$220, U$294, U$368, U$442, U$516, U$590, U$664, U$738, U$812, U$886, U$960, U$1034, U$1108: CONTAINS_FCC_ID#_2AL5J#1801000
U$23, U$147, U$221, U$295, U$369, U$443, U$517, U$591, U$665, U$739, U$813, U$887, U$961, U$1035, U$1109: CONTAINS_IC#_22729#1801000
U$24, U$148, U$222, U$296, U$370, U$444, U$518, U$592, U$666, U$740, U$814, U$888, U$962, U$1036, U$1110: #RTS#0
U$25, U$65, U$149, U$223, U$297, U$371, U$445, U$519, U$593, U$667, U$741, U$815, U$889, U$963, U$1037: SFE_LOGO_FLAME_.2
U$26, U$64, U$150, U$224, U$298, U$372, U$446, U$520, U$594, U$668, U$742, U$816, U$890, U$964, U$1038: FOUR_LAYER_WARNING
U$27, U$66, U$151, U$225, U$299, U$373, U$447, U$521, U$595, U$669, U$743, U$817, U$891, U$965, U$1039: 160
U$28, U$134, U$208, U$282, U$356, U$430, U$504, U$578, U$652, U$726, U$800, U$874, U$948, U$1022, U$1096: #GND#0
U$29, U$135, U$209, U$283, U$357, U$431, U$505, U$579, U$653, U$727, U$801, U$875, U$949, U$1023, U$1097: #NC#0
U$30, U$136, U$210, U$284, U$358, U$432, U$506, U$580, U$654, U$728, U$802, U$876, U$950, U$1024, U$1098: #3V3#0
U$31, U$137, U$211, U$285, U$359, U$433, U$507, U$581, U$655, U$729, U$803, U$877, U$951, U$1025, U$1099: ##RESET##0
U$32, U$138, U$212, U$286, U$360, U$434, U$508, U$582, U$656, U$730, U$804, U$878, U$952, U$1026, U$1100: #LED#0
U$33, U$140, U$214, U$288, U$362, U$436, U$510, U$584, U$658, U$732, U$806, U$880, U$954, U$1028, U$1102: #A0#19#0
U$34, U$139, U$213, U$287, U$361, U$435, U$509, U$583, U$657, U$731, U$805, U$879, U$953, U$1027, U$1101: #ISO#0
U$35, U$141, U$215, U$289, U$363, U$437, U$511, U$585, U$659, U$733, U$807, U$881, U$955, U$1029, U$1103: #A1#20#0
U$36, U$142, U$216, U$290, U$364, U$438, U$512, U$586, U$660, U$734, U$808, U$882, U$956, U$1030, U$1104: #A2#21#0
U$37, U$143, U$217, U$291, U$365, U$439, U$513, U$587, U$661, U$735, U$809, U$883, U$957, U$1031, U$1105: #A3#22#0
U$38, U$144, U$218, U$292, U$366, U$440, U$514, U$588, U$662, U$736, U$810, U$884, U$958, U$1032, U$1106: #A4#23#0
U$39, U$145, U$219, U$293, U$367, U$441, U$515, U$589, U$663, U$737, U$811, U$885, U$959, U$1033, U$1107: #A5#24#0
U$40, U$69, U$152, U$226, U$300, U$374, U$448, U$522, U$596, U$670, U$744, U$818, U$892, U$966, U$1040: 170
U$41, U$70, U$153, U$227, U$301, U$375, U$449, U$523, U$597, U$671, U$745, U$819, U$893, U$967, U$1041: 30
U$42, U$71, U$154, U$228, U$302, U$376, U$450, U$524, U$598, U$672, U$746, U$820, U$894, U$968, U$1042: 40
U$43, U$72, U$155, U$229, U$303, U$377, U$451, U$525, U$599, U$673, U$747, U$821, U$895, U$969, U$1043: 50
U$44, U$73, U$156, U$230, U$304, U$378, U$452, U$526, U$600, U$674, U$748, U$822, U$896, U$970, U$1044: 60
U$45, U$74, U$157, U$231, U$305, U$379, U$453, U$527, U$601, U$675, U$749, U$823, U$897, U$971, U$1045: 70
U$46, U$75, U$158, U$232, U$306, U$380, U$454, U$528, U$602, U$676, U$750, U$824, U$898, U$972, U$1046: 80
U$47, U$76, U$159, U$233, U$307, U$381, U$455, U$529, U$603, U$677, U$751, U$825, U$899, U$973, U$1047: 90
U$48, U$78, U$160, U$234, U$308, U$382, U$456, U$530, U$604, U$678, U$752, U$826, U$900, U$974, U$1048: EN0
U$49, U$79, U$161, U$235, U$309, U$383, U$457, U$531, U$605, U$679, U$753, U$827, U$901, U$975, U$1049: VBAT0
U$50, U$80, U$162, U$236, U$310, U$384, U$458, U$532, U$606, U$680, U$754, U$828, U$902, U$976, U$1050: 20
U$51, U$81, U$163, U$237, U$311, U$385, U$459, U$533, U$607, U$681, U$755, U$829, U$903, U$977, U$1051: 10
U$52, U$82, U$164, U$238, U$312, U$386, U$460, U$534, U$608, U$682, U$756, U$830, U$904, U$978, U$1052: 00
U$53, U$83, U$165, U$239, U$313, U$387, U$461, U$535, U$609, U$683, U$757, U$831, U$905, U$979, U$1053: 120
U$54, U$84, U$166, U$240, U$314, U$388, U$462, U$536, U$610, U$684, U$758, U$832, U$906, U$980, U$1054: 110
U$55, U$85, U$167, U$241, U$315, U$389, U$463, U$537, U$611, U$685, U$759, U$833, U$907, U$981, U$1055: 130
U$56, U$86, U$168, U$242, U$316, U$390, U$464, U$538, U$612, U$686, U$760, U$834, U$908, U$982, U$1056: A50
U$57, U$87, U$169, U$243, U$317, U$391, U$465, U$539, U$613, U$687, U$761, U$835, U$909, U$983, U$1057: A40
U$58, U$88, U$170, U$244, U$318, U$392, U$466, U$540, U$614, U$688, U$762, U$836, U$910, U$984, U$1058: A30
U$59, U$89, U$171, U$245, U$319, U$393, U$467, U$541, U$615, U$689, U$763, U$837, U$911, U$985, U$1059: A20
U$60, U$90, U$172, U$246, U$320, U$394, U$468, U$542, U$616, U$690, U$764, U$838, U$912, U$986, U$1060: A10
U$61, U$91, U$173, U$247, U$321, U$395, U$469, U$543, U$617, U$691, U$765, U$839, U$913, U$987, U$1061: A00
U$62, U$108, U$182, U$256, U$330, U$404, U$478, U$552, U$626, U$700, U$774, U$848, U$922, U$996, U$1070: 180
U$63, U$92, U$174, U$248, U$322, U$396, U$470, U$544, U$618, U$692, U$766, U$840, U$914, U$988, U$1062: GND0
U$67, U$109, U$183, U$257, U$331, U$405, U$479, U$553, U$627, U$701, U$775, U$849, U$923, U$997, U$1071: CHG0
U$68, U$110, U$184, U$258, U$332, U$406, U$480, U$554, U$628, U$702, U$776, U$850, U$924, U$998, U$1072: PWR0
U$77, U$93, U$175, U$249, U$323, U$397, U$471, U$545, U$619, U$693, U$767, U$841, U$915, U$989, U$1063: NC0
U$94, U$102, U$176, U$250, U$324, U$398, U$472, U$546, U$620, U$694, U$768, U$842, U$916, U$990, U$1064: 3V30
U$95, U$103, U$177, U$251, U$325, U$399, U$473, U$547, U$621, U$695, U$769, U$843, U$917, U$991, U$1065: #RST#0
U$96, U$104, U$178, U$252, U$326, U$400, U$474, U$548, U$622, U$696, U$770, U$844, U$918, U$992, U$1066: RST0
U$97, U$105, U$179, U$253, U$327, U$401, U$475, U$549, U$623, U$697, U$771, U$845, U$919, U$993, U$1067: 100
U$98, U$106, U$180, U$254, U$328, U$402, U$476, U$550, U$624, U$698, U$772, U$846, U$920, U$994, U$1068: #0
U$99, U$107, U$181, U$255, U$329, U$403, U$477, U$551, U$625, U$699, U$773, U$847, U$921, U$995, U$1069: #_0
U$100, U$111, U$185, U$259, U$333, U$407, U$481, U$555, U$629, U$703, U$777, U$851, U$925, U$999, U$1073: RX0
U$101, U$112, U$186, U$260, U$334, U$408, U$482, U$556, U$630, U$704, U$778, U$852, U$926, U$1000, U$1074: TX0
Y1, Y2, Y3, Y4, Y5, Y6, Y7, Y8, Y9, Y10, Y11, Y12, Y13, Y14, Y15: 32.768kHz; CRYSTAL-SMD-3.2X1.5MM

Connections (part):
3.3V: C5.1, C8.1, C9.1, C10.1, C11.1, C12.1, ISO.1, J2.1, J4.2, J6.2, LED.2, R7.2, R8.2, R11.2, U3.H2, U3.H4, U3.H6, U3.H8, U4.7, U4.10
3.3V1: C19.1, C20.1, C21.1, C22.1, C23.1, C28.1, ISO1.1, J10.1, J11.2, J13.2, LED1.2, R15.2, R17.2, R18.2, U8.7, U8.10, U9.H2, U9.H4, U9.H6, U9.H8
3.3V2: C35.1, C36.1, C37.1, C38.1, C39.1, C44.1, ISO2.1, J17.1, J18.2, J20.2, LED2.2, R26.2, R28.2, R29.2, U13.7, U13.10, U14.H2, U14.H4, U14.H6, U14.H8
3.3V3: C51.1, C52.1, C53.1, C54.1, C55.1, C60.1, ISO3.1, J24.1, J25.2, J27.2, LED3.2, R37.2, R39.2, R40.2, U18.7, U18.10, U19.H2, U19.H4, U19.H6, U19.H8
3.3V4: C67.1, C68.1, C69.1, C70.1, C71.1, C76.1, ISO4.1, J31.1, J32.2, J34.2, LED4.2, R48.2, R50.2, R51.2, U23.7, U23.10, U24.H2, U24.H4, U24.H6, U24.H8
3.3V5: C83.1, C84.1, C85.1, C86.1, C87.1, C92.1, ISO5.1, J38.1, J39.2, J41.2, LED5.2, R59.2, R61.2, R62.2, U28.7, U28.10, U29.H2, U29.H4, U29.H6, U29.H8
3.3V6: C99.1, C100.1, C101.1, C102.1, C103.1, C108.1, ISO6.1, J45.1, J46.2, J48.2, LED6.2, R70.2, R72.2, R73.2, U33.7, U33.10, U34.H2, U34.H4, U34.H6, U34.H8
3.3V7: C115.1, C116.1, C117.1, C118.1, C119.1, C124.1, ISO7.1, J52.1, J53.2, J55.2, LED7.2, R81.2, R83.2, R84.2, U38.7, U38.10, U39.H2, U39.H4, U39.H6, U39.H8
3.3V8: C131.1, C132.1, C133.1, C134.1, C135.1, C140.1, ISO8.1, J59.1, J60.2, J62.2, LED8.2, R92.2, R94.2, R95.2, U43.7, U43.10, U44.H2, U44.H4, U44.H6, U44.H8
3.3V9: C147.1, C148.1, C149.1, C150.1, C151.1, C156.1, ISO9.1, J66.1, J67.2, J69.2, LED9.2, R103.2, R105.2, R106.2, U48.7, U48.10, U49.H2, U49.H4, U49.H6, U49.H8
3.3V10: C163.1, C164.1, C165.1, C166.1, C167.1, C172.1, ISO10.1, J73.1, J74.2, J76.2, LED10.2, R114.2, R116.2, R117.2, U53.7, U53.10, U54.H2, U54.H4, U54.H6, U54.H8
3.3V11: C179.1, C180.1, C181.1, C182.1, C183.1, C188.1, ISO11.1, J80.1, J81.2, J83.2, LED11.2, R125.2, R127.2, R128.2, U58.7, U58.10, U59.H2, U59.H4, U59.H6, U59.H8
3.3V12: C195.1, C196.1, C197.1, C198.1, C199.1, C204.1, ISO12.1, J87.1, J88.2, J90.2, LED12.2, R136.2, R138.2, R139.2, U63.7, U63.10, U64.H2, U64.H4, U64.H6, U64.H8
3.3V13: C211.1, C212.1, C213.1, C214.1, C215.1, C220.1, ISO13.1, J94.1, J95.2, J97.2, LED13.2, R147.2, R149.2, R150.2, U68.7, U68.10, U69.H2, U69.H4, U69.H6, U69.H8
3.3V14: C227.1, C228.1, C229.1, C230.1, C231.1, C236.1, ISO14.1, J101.1, J102.2, J104.2, LED14.2, R158.2, R160.2, R161.2, U73.7, U73.10, U74.H2, U74.H4, U74.H6, U74.H8
!RESET: C1.2, C15.1, J2.10, J4.1, R11.1, S1.3, S1.4, U3.C1
!RESET1: C24.1, C31.2, J10.10, J13.1, R17.1, S3.3, S3.4, U9.C1
!RESET2: C40.1, C47.2, J17.10, J20.1, R28.1, S5.3, S5.4, U14.C1
!RESET3: C56.1, C63.2, J24.10, J27.1, R39.1, S7.3, S7.4, U19.C1
!RESET4: C72.1, C79.2, J31.10, J34.1, R50.1, S9.3, S9.4, U24.C1
!RESET5: C88.1, C95.2, J38.10, J41.1, R61.1, S11.3, S11.4, U29.C1
!RESET6: C104.1, C111.2, J45.10, J48.1, R72.1, S13.3, S13.4, U34.C1
!RESET7: C120.1, C127.2, J52.10, J55.1, R83.1, S15.3, S15.4, U39.C1
!RESET8: C136.1, C143.2, J59.10, J62.1, R94.1, S17.3, S17.4, U44.C1
!RESET9: C152.1, C159.2, J66.10, J69.1, R105.1, S19.3, S19.4, U49.C1
!RESET10: C168.1, C175.2, J73.10, J76.1, R116.1, S21.3, S21.4, U54.C1
!RESET11: C184.1, C191.2, J80.10, J83.1, R127.1, S23.3, S23.4, U59.C1
!RESET12: C200.1, C207.2, J87.10, J90.1, R138.1, S25.3, S25.4, U64.C1
!RESET13: C216.1, C223.2, J94.10, J97.1, R149.1, S27.3, S27.4, U69.C1
!RESET14: C232.1, C239.2, J101.10, J104.1, R160.1, S29.3, S29.4, U74.C1
!RTS: RTS.1, U4.4
!RTS1: RTS1.1, U8.4
!RTS2: RTS2.1, U13.4
!RTS3: RTS3.1, U18.4
!RTS4: RTS4.1, U23.4
!RTS5: RTS5.1, U28.4
!RTS6: RTS6.1, U33.4
!RTS7: RTS7.1, U38.4
!RTS8: RTS8.1, U43.4
!RTS9: RTS9.1, U48.4
!RTS10: RTS10.1, U53.4
!RTS11: RTS11.1, U58.4
!RTS12: RTS12.1, U63.4
!RTS13: RTS13.1, U68.4
!RTS14: RTS14.1, U73.4
BOOT: C13.2, R10.2, U3.J7
BOOT1: C32.2, R22.2, U9.J7
BOOT2: C48.2, R33.2, U14.J7
BOOT3: C64.2, R44.2, U19.J7
BOOT4: C80.2, R55.2, U24.J7
BOOT5: C96.2, R66.2, U29.J7
BOOT6: C112.2, R77.2, U34.J7
BOOT7: C128.2, R88.2, U39.J7
BOOT8: C144.2, R99.2, U44.J7
BOOT9: C160.2, R110.2, U49.J7
BOOT10: C176.2, R121.2, U54.J7
BOOT11: C192.2, R132.2, U59.J7
BOOT12: C208.2, R143.2, U64.J7
BOOT13: C224.2, R154.2, U69.J7
BOOT14: C240.2, R165.2, U74.J7
BT_RF: C17.1, U3.A5
BT_RF1: C30.1, U9.A5
BT_RF2: C46.1, U14.A5
BT_RF3: C62.1, U19.A5
BT_RF4: C78.1, U24.A5
BT_RF5: C94.1, U29.A5
BT_RF6: C110.1, U34.A5
BT_RF7: C126.1, U39.A5
BT_RF8: C142.1, U44.A5
BT_RF9: C158.1, U49.A5
BT_RF10: C174.1, U54.A5
BT_RF11: C190.1, U59.A5
BT_RF12: C206.1, U64.A5
BT_RF13: C222.1, U69.A5
BT_RF14: C238.1, U74.A5
CC1: J5.A5, R6.2
CC2: J5.B5, R5.2
CC3: J9.B5, R14.2
CC4: J9.A5, R16.2
CC5: J16.B5, R25.2
CC6: J16.A5, R27.2
CC7: J23.B5, R36.2
CC8: J23.A5, R38.2
CC9: J30.B5, R47.2
CC10: J30.A5, R49.2
CC11: J37.B5, R58.2
CC12: J37.A5, R60.2
CC13: J44.B5, R69.2
CC14: J44.A5, R71.2
CC15: J51.B5, R80.2
CC16: J51.A5, R82.2
CC17: J58.B5, R91.2
CC18: J58.A5, R93.2
CC19: J65.B5, R102.2
CC20: J65.A5, R104.2
CC21: J72.B5, R113.2
CC22: J72.A5, R115.2
CC23: J79.B5, R124.2
CC24: J79.A5, R126.2
CC25: J86.B5, R135.2
CC26: J86.A5, R137.2
CC27: J93.B5, R146.2
CC28: J93.A5, R148.2
CC29: J100.B5, R157.2
CC30: J100.A5, R159.2
D10/SWCH: S2.1, S2.2, U3.J6
D10/SWCH1: S4.1, S4.2, U9.J6
D10/SWCH2: S6.1, S6.2, U14.J6
D10/SWCH3: S8.1, S8.2, U19.J6
D10/SWCH4: S10.1, S10.2, U24.J6
D10/SWCH5: S12.1, S12.2, U29.J6
D10/SWCH6: S14.1, S14.2, U34.J6
D10/SWCH7: S16.1, S16.2, U39.J6
D10/SWCH8: S18.1, S18.2, U44.J6
D10/SWCH9: S20.1, S20.2, U49.J6
D10/SWCH10: S22.1, S22.2, U54.J6
D10/SWCH11: S24.1, S24.2, U59.J6
D10/SWCH12: S26.1, S26.2, U64.J6
D10/SWCH13: S28.1, S28.2, U69.J6
D10/SWCH14: S30.1, S30.2, U74.J6
D14/QWIIC_SDA: J6.3, TP5.P$1, U3.G1
D14/QWIIC_SDA1: J11.3, TP10.P$1, U9.G1
D14/QWIIC_SDA2: J18.3, TP16.P$1, U14.G1
D14/QWIIC_SDA3: J25.3, TP22.P$1, U19.G1
D14/QWIIC_SDA4: J32.3, TP28.P$1, U24.G1
D14/QWIIC_SDA5: J39.3, TP34.P$1, U29.G1
D14/QWIIC_SDA6: J46.3, TP40.P$1, U34.G1
D14/QWIIC_SDA7: J53.3, TP46.P$1, U39.G1
D14/QWIIC_SDA8: J60.3, TP52.P$1, U44.G1
D14/QWIIC_SDA9: J67.3, TP58.P$1, U49.G1
D14/QWIIC_SDA10: J74.3, TP64.P$1, U54.G1
D14/QWIIC_SDA11: J81.3, TP70.P$1, U59.G1
D14/QWIIC_SDA12: J88.3, TP76.P$1, U64.G1
D14/QWIIC_SDA13: J95.3, TP82.P$1, U69.G1
D14/QWIIC_SDA14: J102.3, TP88.P$1, U74.G1
D+1: J5.A6, J5.B6, U4.1
D+2: J9.A6, J9.B6, U8.1
D+3: J16.A6, J16.B6, U13.1
D+4: J23.A6, J23.B6, U18.1
D+5: J30.A6, J30.B6, U23.1
D+6: J37.A6, J37.B6, U28.1
D+7: J44.A6, J44.B6, U33.1
D+8: J51.A6, J51.B6, U38.1
D+9: J58.A6, J58.B6, U43.1
D+10: J65.A6, J65.B6, U48.1
D+11: J72.A6, J72.B6, U53.1
D+12: J79.A6, J79.B6, U58.1
D+13: J86.A6, J86.B6, U63.1
D+14: J93.A6, J93.B6, U68.1
D+15: J100.A6, J100.B6, U73.1
D-1: J5.A7, J5.B7, U4.2
D-2: J9.A7, J9.B7, U8.2
D-3: J16.A7, J16.B7, U13.2
D-4: J23.A7, J23.B7, U18.2
D-5: J30.A7, J30.B7, U23.2
D-6: J37.A7, J37.B7, U28.2
D-7: J44.A7, J44.B7, U33.2
D-8: J51.A7, J51.B7, U38.2
D-9: J58.A7, J58.B7, U43.2
D-10: J65.A7, J65.B7, U48.2
D-11: J72.A7, J72.B7, U53.2
D-12: J79.A7, J79.B7, U58.2
D-13: J86.A7, J86.B7, U63.2
D-14: J93.A7, J93.B7, U68.2
D-15: J100.A7, J100.B7, U73.2
EN: J3.2, R3.1, U2.3
EN1: J12.2, R9.1, U7.3
EN2: J19.2, R23.1, U12.3
EN3: J26.2, R34.1, U17.3
EN4: J33.2, R45.1, U22.3
EN5: J40.2, R56.1, U27.3
EN6: J47.2, R67.1, U32.3
EN7: J54.2, R78.1, U37.3
EN8: J61.2, R89.1, U42.3
EN9: J68.2, R100.1, U47.3
EN10: J75.2, R111.1, U52.3
EN11: J82.2, R122.1, U57.3
EN12: J89.2, R133.1, U62.3
EN13: J96.2, R144.1, U67.3
EN14: J103.2, R155.1, U72.3
GND: C2.2, C3.2, C4.2, C5.2, C6.1, C7.1, C8.2, C9.2, C10.2, C11.2, C12.2, C15.2, D4.C, D7.C, J1.1, J2.3, J2.5, J2.9, J4.4, J5.GND, J5.GND2, J6.1, J8.1, J8.2, R2.1, R5.1, R6.1, R10.1, S1.1, S1.2, S2.3, S2.4, U1.2, U2.2, U3.A2, U3.A4, U3.A6, U3.B1, U3.B2, U3.B3, U3.B4, U3.B5, U3.B6, U3.B7, U3.D1, U3.D4, U3.D5, U3.D6, U3.D9, U3.E4, U3.E5, U3.E6, U3.F4, U3.F5, U3.F6, U3.H3, U3.H5, U3.H7, U3.J1, U3.J9, U4.3, U6.1, U6.3, U6.5
GND1: C14.1, C18.1, C19.2, C20.2, C21.2, C22.2, C23.2, C24.2, C25.2, C26.2, C27.2, C28.2, D8.C, D13.C, J7.1, J9.GND, J9.GND2, J10.3, J10.5, J10.9, J11.1, J13.4, J14.1, J14.2, R14.1, R16.1, R20.1, R22.1, S3.1, S3.2, S4.3, S4.4, U5.2, U7.2, U8.3, U9.A2, U9.A4, U9.A6, U9.B1, U9.B2, U9.B3, U9.B4, U9.B5, U9.B6, U9.B7, U9.D1, U9.D4, U9.D5, U9.D6, U9.D9, U9.E4, U9.E5, U9.E6, U9.F4, U9.F5, U9.F6, U9.H3, U9.H5, U9.H7, U9.J1, U9.J9, U10.1, U10.3, U10.5
GND2: C33.1, C34.1, C35.2, C36.2, C37.2, C38.2, C39.2, C40.2, C41.2, C42.2, C43.2, C44.2, D15.C, D20.C, J15.1, J16.GND, J16.GND2, J17.3, J17.5, J17.9, J18.1, J20.4, J21.1, J21.2, R25.1, R27.1, R31.1, R33.1, S5.1, S5.2, S6.3, S6.4, U11.2, U12.2, U13.3, U14.A2, U14.A4, U14.A6, U14.B1, U14.B2, U14.B3, U14.B4, U14.B5, U14.B6, U14.B7, U14.D1, U14.D4, U14.D5, U14.D6, U14.D9, U14.E4, U14.E5, U14.E6, U14.F4, U14.F5, U14.F6, U14.H3, U14.H5, U14.H7, U14.J1, U14.J9, U15.1, U15.3, U15.5
GND3: C49.1, C50.1, C51.2, C52.2, C53.2, C54.2, C55.2, C56.2, C57.2, C58.2, C59.2, C60.2, D22.C, D27.C, J22.1, J23.GND, J23.GND2, J24.3, J24.5, J24.9, J25.1, J27.4, J28.1, J28.2, R36.1, R38.1, R42.1, R44.1, S7.1, S7.2, S8.3, S8.4, U16.2, U17.2, U18.3, U19.A2, U19.A4, U19.A6, U19.B1, U19.B2, U19.B3, U19.B4, U19.B5, U19.B6, U19.B7, U19.D1, U19.D4, U19.D5, U19.D6, U19.D9, U19.E4, U19.E5, U19.E6, U19.F4, U19.F5, U19.F6, U19.H3, U19.H5, U19.H7, U19.J1, U19.J9, U20.1, U20.3, U20.5
GND4: C65.1, C66.1, C67.2, C68.2, C69.2, C70.2, C71.2, C72.2, C73.2, C74.2, C75.2, C76.2, D29.C, D34.C, J29.1, J30.GND, J30.GND2, J31.3, J31.5, J31.9, J32.1, J34.4, J35.1, J35.2, R47.1, R49.1, R53.1, R55.1, S9.1, S9.2, S10.3, S10.4, U21.2, U22.2, U23.3, U24.A2, U24.A4, U24.A6, U24.B1, U24.B2, U24.B3, U24.B4, U24.B5, U24.B6, U24.B7, U24.D1, U24.D4, U24.D5, U24.D6, U24.D9, U24.E4, U24.E5, U24.E6, U24.F4, U24.F5, U24.F6, U24.H3, U24.H5, U24.H7, U24.J1, U24.J9, U25.1, U25.3, U25.5
GND5: C81.1, C82.1, C83.2, C84.2, C85.2, C86.2, C87.2, C88.2, C89.2, C90.2, C91.2, C92.2, D36.C, D41.C, J36.1, J37.GND, J37.GND2, J38.3, J38.5, J38.9, J39.1, J41.4, J42.1, J42.2, R58.1, R60.1, R64.1, R66.1, S11.1, S11.2, S12.3, S12.4, U26.2, U27.2, U28.3, U29.A2, U29.A4, U29.A6, U29.B1, U29.B2, U29.B3, U29.B4, U29.B5, U29.B6, U29.B7, U29.D1, U29.D4, U29.D5, U29.D6, U29.D9, U29.E4, U29.E5, U29.E6, U29.F4, U29.F5, U29.F6, U29.H3, U29.H5, U29.H7, U29.J1, U29.J9, U30.1, U30.3, U30.5
GND6: C97.1, C98.1, C99.2, C100.2, C101.2, C102.2, C103.2, C104.2, C105.2, C106.2, C107.2, C108.2, D43.C, D48.C, J43.1, J44.GND, J44.GND2, J45.3, J45.5, J45.9, J46.1, J48.4, J49.1, J49.2, R69.1, R71.1, R75.1, R77.1, S13.1, S13.2, S14.3, S14.4, U31.2, U32.2, U33.3, U34.A2, U34.A4, U34.A6, U34.B1, U34.B2, U34.B3, U34.B4, U34.B5, U34.B6, U34.B7, U34.D1, U34.D4, U34.D5, U34.D6, U34.D9, U34.E4, U34.E5, U34.E6, U34.F4, U34.F5, U34.F6, U34.H3, U34.H5, U34.H7, U34.J1, U34.J9, U35.1, U35.3, U35.5
GND7: C113.1, C114.1, C115.2, C116.2, C117.2, C118.2, C119.2, C120.2, C121.2, C122.2, C123.2, C124.2, D50.C, D55.C, J50.1, J51.GND, J51.GND2, J52.3, J52.5, J52.9, J53.1, J55.4, J56.1, J56.2, R80.1, R82.1, R86.1, R88.1, S15.1, S15.2, S16.3, S16.4, U36.2, U37.2, U38.3, U39.A2, U39.A4, U39.A6, U39.B1, U39.B2, U39.B3, U39.B4, U39.B5, U39.B6, U39.B7, U39.D1, U39.D4, U39.D5, U39.D6, U39.D9, U39.E4, U39.E5, U39.E6, U39.F4, U39.F5, U39.F6, U39.H3, U39.H5, U39.H7, U39.J1, U39.J9, U40.1, U40.3, U40.5
GND8: C129.1, C130.1, C131.2, C132.2, C133.2, C134.2, C135.2, C136.2, C137.2, C138.2, C139.2, C140.2, D57.C, D62.C, J57.1, J58.GND, J58.GND2, J59.3, J59.5, J59.9, J60.1, J62.4, J63.1, J63.2, R91.1, R93.1, R97.1, R99.1, S17.1, S17.2, S18.3, S18.4, U41.2, U42.2, U43.3, U44.A2, U44.A4, U44.A6, U44.B1, U44.B2, U44.B3, U44.B4, U44.B5, U44.B6, U44.B7, U44.D1, U44.D4, U44.D5, U44.D6, U44.D9, U44.E4, U44.E5, U44.E6, U44.F4, U44.F5, U44.F6, U44.H3, U44.H5, U44.H7, U44.J1, U44.J9, U45.1, U45.3, U45.5
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

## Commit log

2020-10-05 Schematic Updated
    [Artemis Thing Plus.brd, Artemis Thing Plus.sch]
2020-10-08 Added 4-layer board
    [MacawBlue Thing Plus.brd, MacawBlue Thing Plus.sch]
2020-10-13 Fixed NM180100 footprint
    [MacawBlue Thing Plus.brd, MacawBlue Thing Plus.sch]
2020-10-14 Renamed & rm LoRa reg
    [expLoRaBLE Thing Plus.brd, expLoRaBLE Thing Plus.sch]
2020-10-15 Create prelim board fabrication files
    [Artemis Thing Plus.brd, Artemis Thing Plus.sch, MacawBlue Thing Plus.brd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]
2020-10-15 Update gerbers
2020-10-15 added gerbers
2020-10-21 Made suggested changes
    [bom_output.csv, expLoRaBLE Thing Plus.brd]
2020-10-21 TP and Jumper addition
    [expLoRaBLE Thing Plus.brd, expLoRaBLE Thing Plus.sch]
2020-10-22 Updated labels to buzzard vectors and more minor tweaks
    -also nudged some components near TX LED to make room for silk to avoid nearby mask.
    -added version text object to both sch sheets
    -redrew some sch to avoid 4-way nodes
    -added buzzard label to bottom LED disable jumper
    -moved ISO jumper to trace closed, added top silk label
    -added special ordering instructions with 4-layer board text on tDocu
    [expLoRaBLE Thing Plus.brd, expLoRaBLE Thing Plus.sch]
2020-10-23 repo reorganization and started on readme
    [bom_output.csv, expLoRaBLE Thing Plus.brd, expLoRaBLE Thing Plus.sch]
2020-10-23 Library work, added PROD_IDs to module and diplexer
    [expLoRaBLE Thing Plus.brd, expLoRaBLE Thing Plus.sch]
2020-10-23 added 1/2/3/4 text obejcts in copper layers
    -also manually connected a GND pin on the CH340, due to islation increase it only had one side of the pad flowed. Might as well connect both sides.
    -nudge product name silk on bottom silk to avoid getting cutoff by usb millwork.
    [expLoRaBLE Thing Plus.brd]
2020-10-23 Polarity silk markings added/moved outside package
    [expLoRaBLE Thing Plus.brd, expLoRaBLE Thing Plus.sch]
2020-10-26 Made changes per review meeting, added FCC ID
    [expLoRaBLE Thing Plus.brd, expLoRaBLE Thing Plus.sch]
2020-10-26 Design review changes
    -Updated EN on bottom silk to be input <EN]
    -Updated RESET on bottom silk to be input [!RESET!>
    -Repositioned LED jumper buzzard label
    -changed ISO jumper buzzard label to match inverted text style
    -Updated RX and TX bottom labels to input/output flag type
    -changed FCC info labels to buzzard
    -updated A0-A5 bottom labels to include digital pin number as well.
    -approved jumper drc errors
    -nudged D18 trace on layer 15 to allow for ground pour to connect
    [expLoRaBLE Thing Plus.brd]
2020-10-27 RX/TX labels back to rounded, some minor tweaks to layer 15 for better gnd flow
    -fixed one right angle on layer 15, net D9/A7
    -nudged some traces and vias to allow for better ground flow on all pours
    [expLoRaBLE Thing Plus.brd]
2020-10-28 Added NO jumper for RTS - RESET
    [expLoRaBLE Thing Plus.brd, expLoRaBLE Thing Plus.sch]
2020-10-28 RTS jumper buzzard label
    -renamed jumper to "RTS"
    -added buzzard label
    -also moved user silk "10" to new button position
    [expLoRaBLE Thing Plus.brd, expLoRaBLE Thing Plus.sch]
2020-10-28 checklist run
    -added text blurb explaining optional RTS jumper
    -approved one gnd wire stub off of ch340
    [expLoRaBLE Thing Plus.brd, expLoRaBLE Thing Plus.sch]
2020-10-29 proto gerbers
2020-11-16 Fixed short from 3.3V to GND caused by USB connector mill holes
    Adjusted inner layer polygons to not pour under the USB connector. Previously these were shorting all planes together, causing a short between 3.3V NET and GND NET.
    [expLoRaBLE Thing Plus.brd, expLoRaBLE Thing Plus.sch]
2020-11-18 Updating to USB-C-16P-4-LAYER-ISOLATED
    -This new footprint includes the isolation (aka cutout polygons). It is better to include these at the library lavel (rather than in the board, as it was previously).
    -Note, had to re-route VBUS, because the update also included moving the pads south to match the datasheet. This update commit history to the connector library here: https://github.com/sparkfun/Spark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
    [expLoRaBLE Thing Plus.brd, expLoRaBLE Thing Plus.sch]
2020-12-04 PROD_ID on module update and schematic cleanup
    -The module PROD_ID SKU needed to be updated.
    -all vector fonts in schematic, and then rotation of 32K crysttal and reposition of name/value attributes.
    [expLoRaBLE Thing Plus.brd, expLoRaBLE Thing Plus.sch]
2020-12-04 v10 production gerbers
    [expLoRaBLE Thing Plus-Panel_v10.brd, expLoRaBLE Thing Plus.brd, expLoRaBLE Thing Plus.sch]
2020-12-21 changed RTS jumper to normally closed trace
    -bumped version to v11 in brd and sch
    -adjusted RTS jumper paragraph in sch
    [expLoRaBLE Thing Plus.brd, expLoRaBLE Thing Plus.sch]
2020-12-22 UART pin change
    -changed UART pin selection to match "standard" sparkfun SVL bootloader
    -TXO:GPIO48, RXI:GPIO49
    -Note, also moved "D10" net/button to GPIO4. This will also need to be configured with a custom "info zero" file to configure ASB to work.
    [expLoRaBLE Thing Plus.brd, expLoRaBLE Thing Plus.sch]
2020-12-22 Added Boot net/pin (for ASB)
    -chose a boot pin (GPIO22). Note, we could not use the standard SFE pin of GPIO47, but this can be set during production programming of custom "info.0" binary.
    -connected RTS (post closed jumper) to boot net, including C13 and pull down R10.
    -left D10 on GPIO4 and is separate from boot circuit. It is soley a user button, similar to the Artemis Thing Plus design (although on a different GPIO#).
    [expLoRaBLE Thing Plus.brd, expLoRaBLE Thing Plus.sch]
2020-12-22 Group review changes
    -removed wire stub on 3.3v via
    -adjusted routing off of tx LED
    -Moved 3.3V that was under the "VUSB" silk, to avoid overlap.
    [expLoRaBLE Thing Plus.brd]
2020-12-22 Actual group review changes
    [expLoRaBLE Thing Plus.brd]
2020-12-23 Eng Run of Checklist v11
    -vector fonts in sch corrected
    -updated version number in sheet 2 of sch
    -fixed text overlap on qwiic ra connector value text object
    -changed 1 0.1uF cap to same version (aka PROD_ID) as others to consolodate BOM
    [expLoRaBLE Thing Plus.brd, expLoRaBLE Thing Plus.sch]
2020-12-23 v11 production panel BRD and gerbers
    [expLoRaBLE Thing Plus-Panel_v11.brd]
2021-01-29 removing batch file option
    this is a bit more of a pain than it's worth here, because users may not have "jlink" setup in their PATHs and it also requires sending the device as an argument, where as the device is included in t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

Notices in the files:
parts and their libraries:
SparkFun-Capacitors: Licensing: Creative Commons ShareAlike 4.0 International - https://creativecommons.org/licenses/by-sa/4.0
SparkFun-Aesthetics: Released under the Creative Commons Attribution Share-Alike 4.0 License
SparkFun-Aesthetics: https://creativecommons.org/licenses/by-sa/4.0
